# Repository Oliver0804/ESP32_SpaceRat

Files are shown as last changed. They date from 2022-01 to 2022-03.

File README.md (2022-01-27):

# 此項目參考 
[ElectronicCats/SpaceRat](https://github.com/ElectronicCats/mpu6050)
# 項目內容

參考SpaceRat進行程序開發，於ESP32實現BLE HID為主要功能，
搭配EC12旋轉編碼器與MPU6500進行滑鼠控制。

### 準備材料

- ESP32
- MPU6500 (MPU6050)
- LCD Moudle SSD1308 I2C 0.96
- EC12/11
-
### 接線方式

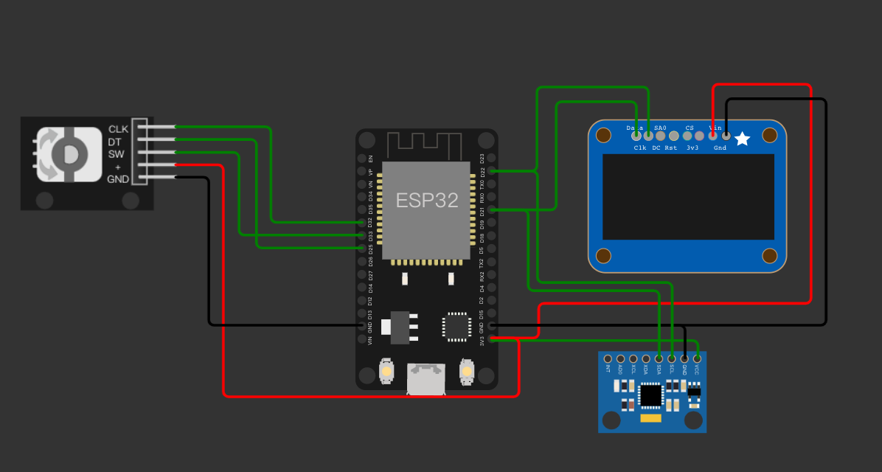
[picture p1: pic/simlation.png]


### TODO List
- [ ] 加速動控制鼠標功能
- [ ] 低功耗機制 需搭配1.5V升壓3.3V
- [ ] OLED選單功能編寫
- [ ] 加速度校正機制

### library安裝
檔案放於Arduino library 

To install this library:

 - install it using the Arduino Library manager ("Sketch" -> "Include
   Library" -> "Manage Libraries..."), or
 - download a zipfile from github using the "Download ZIP" button and
   install it using the IDE ("Sketch" -> "Include Library" -> "Add .ZIP
   Library..."
 - clone this git repository into your sketchbook/libraries folder.

For more info, see https://www.arduino.cc/en/Guide/Libraries

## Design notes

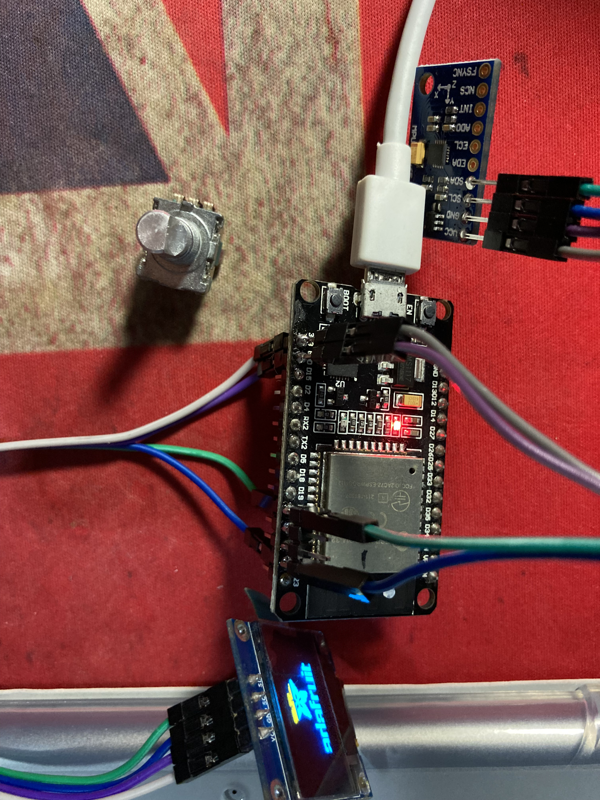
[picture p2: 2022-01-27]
pic/ESP32接線記錄.jpeg

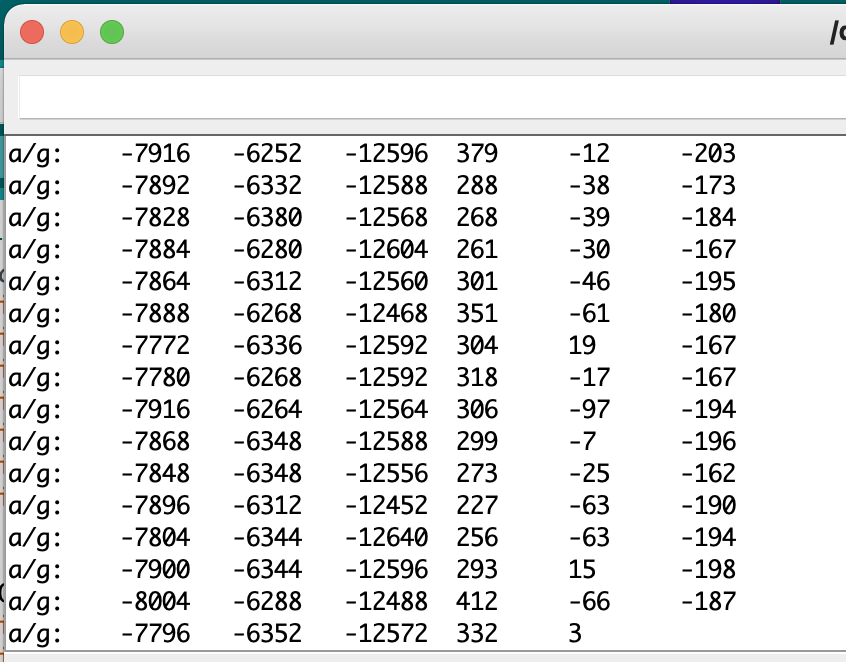
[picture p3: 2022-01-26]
pic/MPU6500數據.png

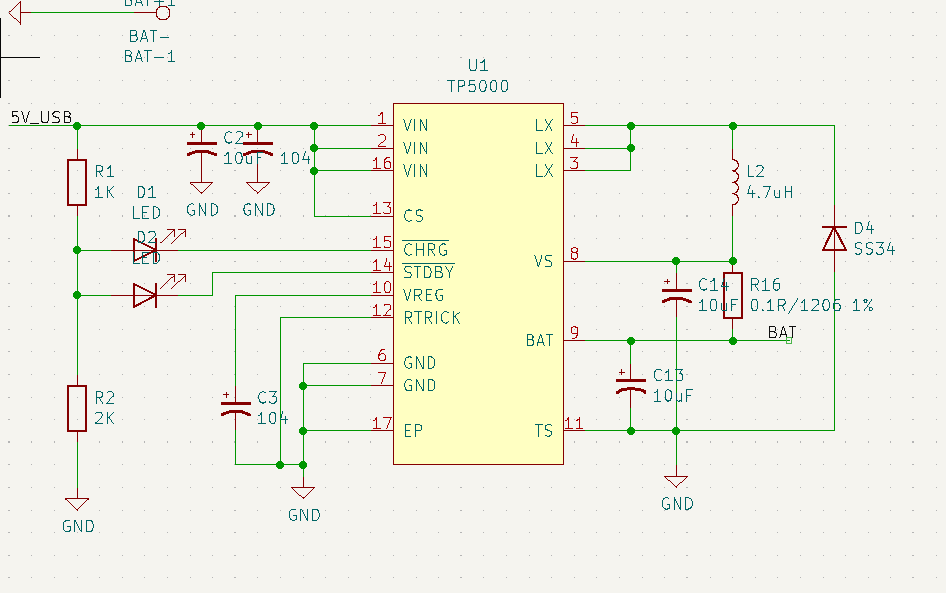
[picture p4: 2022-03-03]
pic/截圖 2022-03-03 下午11.47.27.png

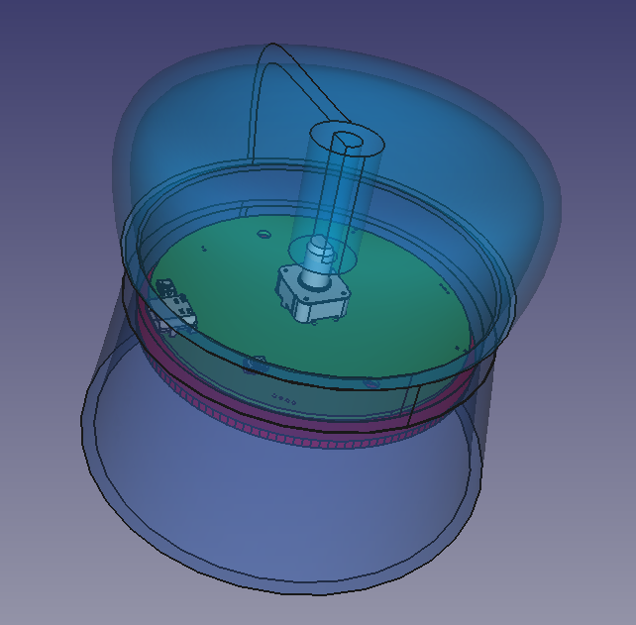
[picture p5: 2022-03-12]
pic/截圖 2022-03-12 下午12.53.13.png

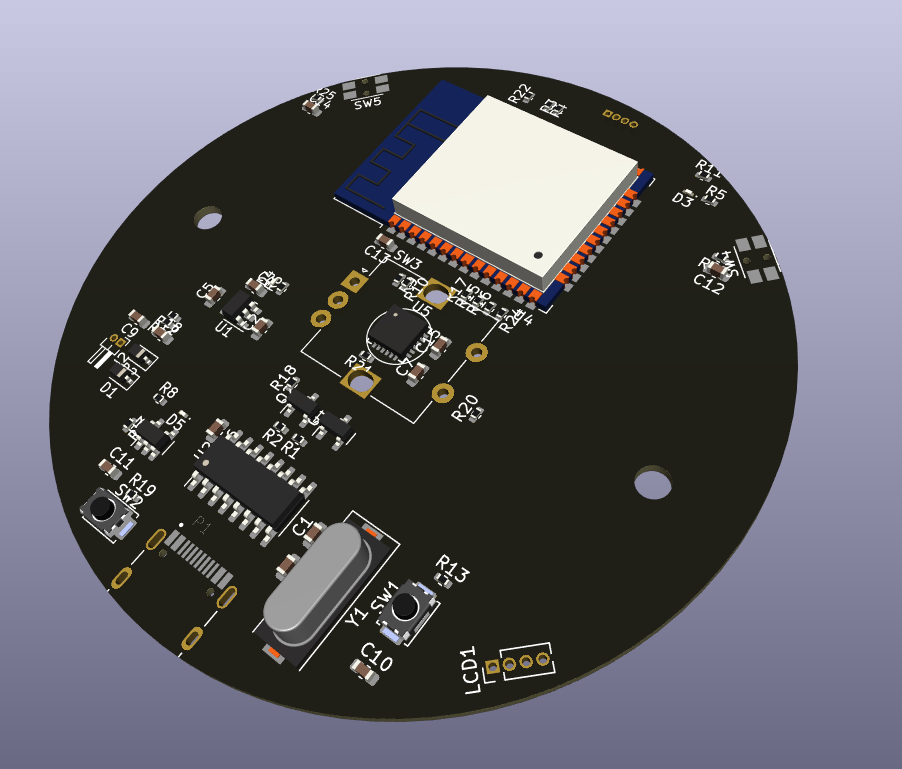
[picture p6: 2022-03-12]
pic/截圖 2022-03-12 下午12.54.49.png

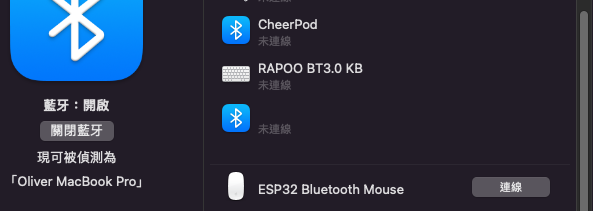
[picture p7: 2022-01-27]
pic/BLEHID測試.png

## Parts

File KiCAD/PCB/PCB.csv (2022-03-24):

Comment | Designator | Footprint | LCSC
22p | C1,C3 | Capacitor_SMD:C_0603_1608Metric
0.1uF | C10,C11,C12,C14,C15 | Capacitor_SMD:C_0603_1608Metric
10nF | C13 | Capacitor_SMD:C_0603_1608Metric
4.7uF | C2,C6,C8 | Capacitor_SMD:C_0603_1608Metric
470pF | C4 | Capacitor_SMD:C_0603_1608Metric
2.2uF | C5 | Capacitor_SMD:C_0603_1608Metric
10uF | C7 | Capacitor_SMD:C_0603_1608Metric
100pF | C9 | Capacitor_SMD:C_0603_1608Metric
D | D1,D2 | Diode_SMD:D_SOD-323
LED | D3,D4,D5 | LED_SMD:LED_0201_0603Metric
Conn_01x04 | J1 | Connector_PinHeader_1.00mm:PinHeader_1x04_P1.00mm_Horizontal
Conn_01x02 | J2 | Connector_PinHeader_1.00mm:PinHeader_1x02_P1.00mm_Horizontal
Conn_01x04 | LCD1 | Connector_PinHeader_1.27mm:PinHeader_1x04_P1.27mm_Vertical
USB_C_Plug | P1 | Connector_USB:HRI_TYPE_C
Q_NPN_EBC | Q1,Q2 | Package_TO_SOT_SMD:SOT-23
R | R1,R2,R5,R6,R15,R16,R17 | Resistor_SMD:R_0402_1005Metric
1M | R12 | Resistor_SMD:R_0402_1005Metric
10K | R13,R19 | Resistor_SMD:R_0402_1005Metric
1MR | R14 | Resistor_SMD:R_0402_1005Metric
10KR | R20 | Resistor_SMD:R_0402_1005Metric
NC | R21 | Resistor_SMD:R_0402_1005Metric
330R | R22,R24 | Resistor_SMD:R_0402_1005Metric
4.7K | R3,R9,R10,R23,R25 | Resistor_SMD:R_0402_1005Metric
1K | R4 | Resistor_SMD:R_0402_1005Metric
2K | R7 | Resistor_SMD:R_0402_1005Metric
470R | R8,R11,R18 | Resistor_SMD:R_0402_1005Metric
SW_Push | SW1,SW2 | Button_Switch_SMD:SW_Push_SPST_NO_Alps_SKRK
RotaryEncoder_Switch | SW3 | Rotary_Encoder:RotaryEncoder_Alps_EC12E-Switch_Vertical_H20mm
SW_Push | SW4,SW5 | Button_Switch_SMD:SW_SPST_EVQP7C
MIC5219-3.3YM5 | U1 | Package_TO_SOT_SMD:SOT-23-5
CH340G | U2 | Package_SO:SOIC-16_3.9x9.9mm_P1.27mm
MCP73832-5-OT | U3 | Package_TO_SOT_SMD:SOT-23-5
ESP32-WROOM-32D | U4 | RF_Module:ESP32-WROOM-32
MPU-6050 | U5 | Sensor_Motion:InvenSense_QFN-24_4x4mm_P0.5mm
12Mhz | Y1 | Crystal:Crystal_SMD_HC49-SD

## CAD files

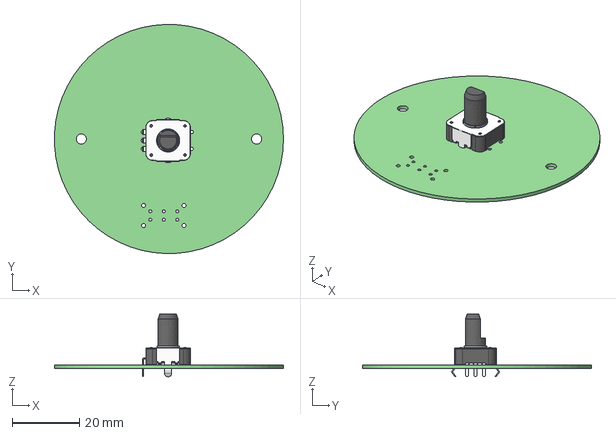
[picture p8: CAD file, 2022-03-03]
KiCAD/PCB/PCB.step
68.0 x 68.0 x 18.6 mm
PCB PCB

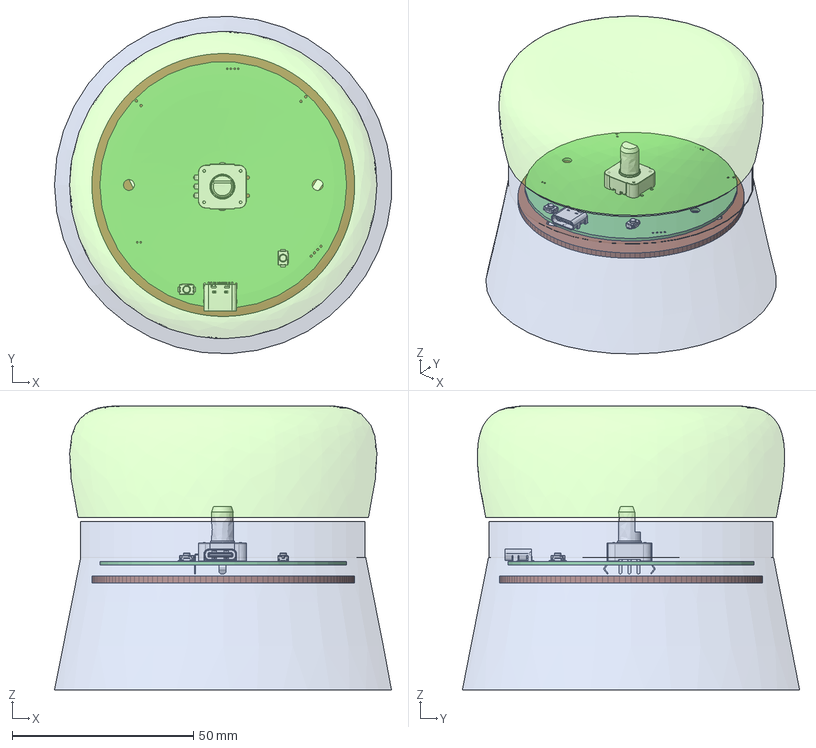
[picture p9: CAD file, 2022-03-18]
STL/dimmer.FCStd
92.8 x 92.9 x 78.2 mm
Orthoplanar_Spring001 (Solid)002
PCB PCB

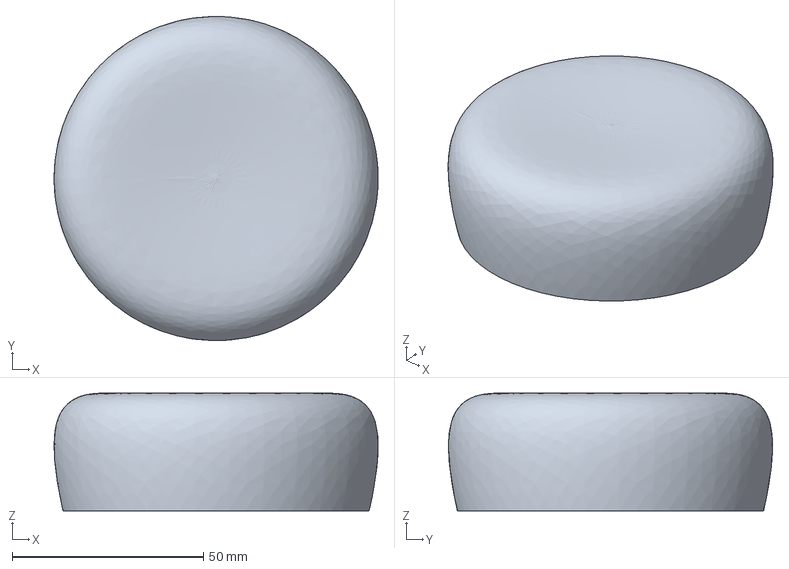
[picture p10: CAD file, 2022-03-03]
STL/蘑菇頭.FCStd
84.6 x 84.6 x 30.8 mm

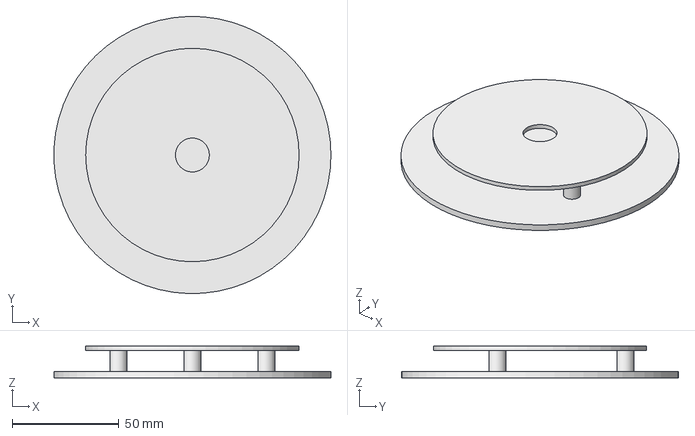
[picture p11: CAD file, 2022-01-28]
STL/SpaceRat.FCStd
129.9 x 130.0 x 15.0 mm

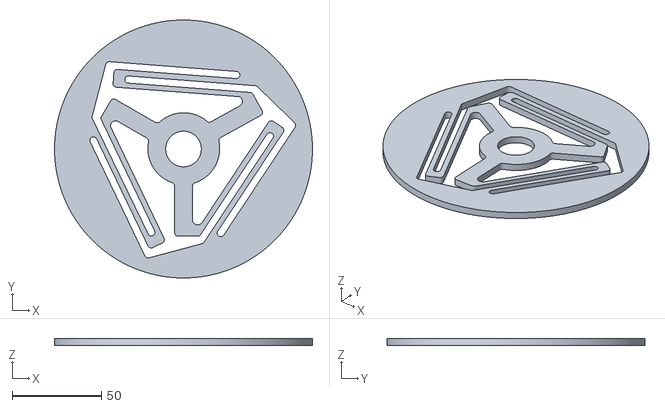
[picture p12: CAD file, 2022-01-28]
STL/Orthoplanar_Spring.stl
144.8 x 144.8 x 3.81

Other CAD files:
STL/Unnamed-Orthoplanar_Spring.dxf

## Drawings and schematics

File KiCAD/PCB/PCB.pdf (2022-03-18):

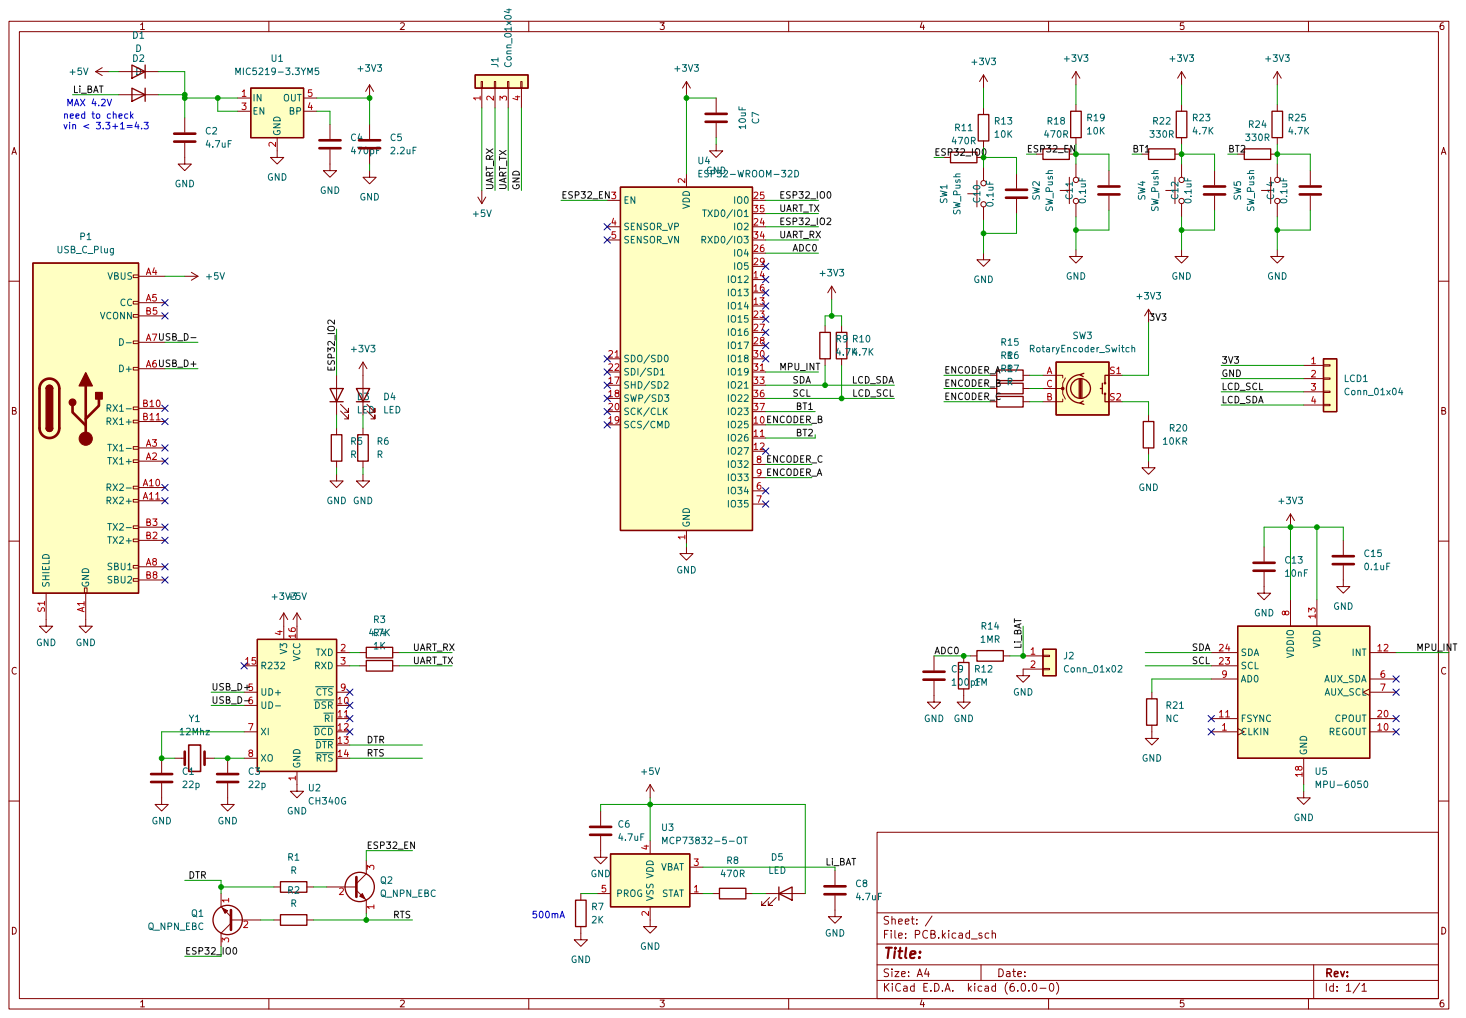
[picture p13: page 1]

2 EN 3 BP 4 OUT 5 U1 MIC5219-3.3YM5 GND C12 0.1uF R20

2 SCK/CLK 20 SDO/SD0 21 SDI/SD1 22

1 ~{DSR}10 ~{RI}11 ~{DCD}12 ~{DTR}13 ~{RTS}14 R232 15 VCC 16 TXD 2 RXD 3 V3

4 UD+ 5 UD- 6 XI 7 XO 8 ~{CTS} 9 U2CH340G

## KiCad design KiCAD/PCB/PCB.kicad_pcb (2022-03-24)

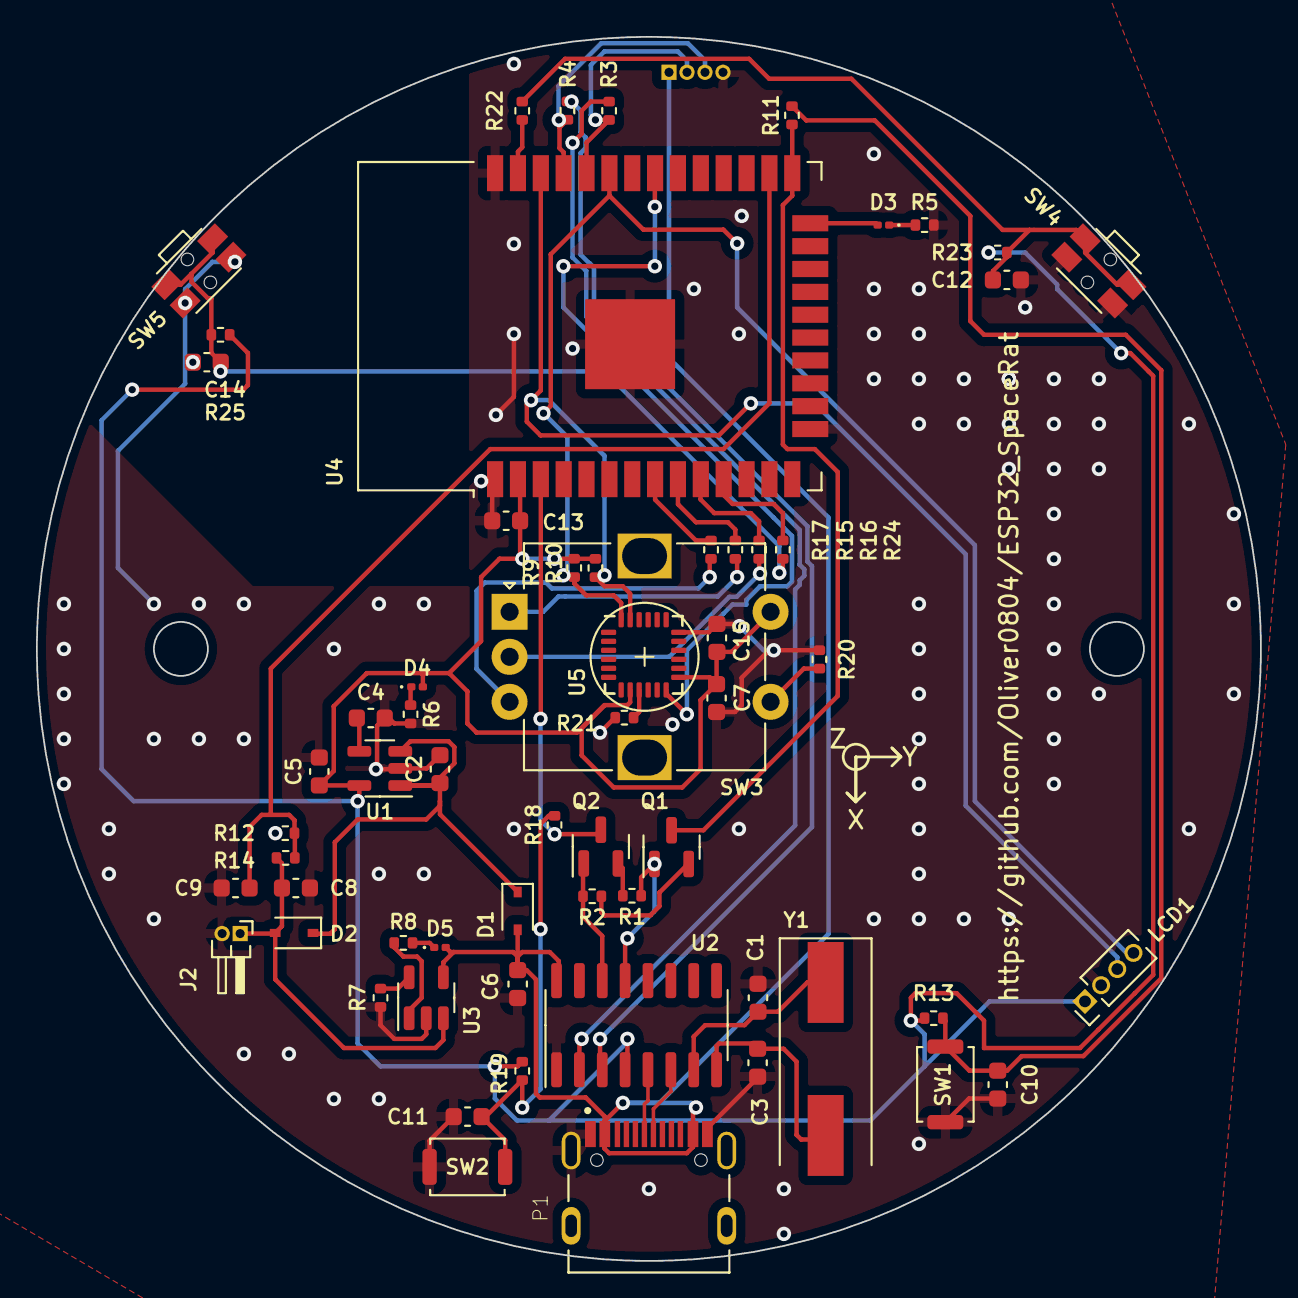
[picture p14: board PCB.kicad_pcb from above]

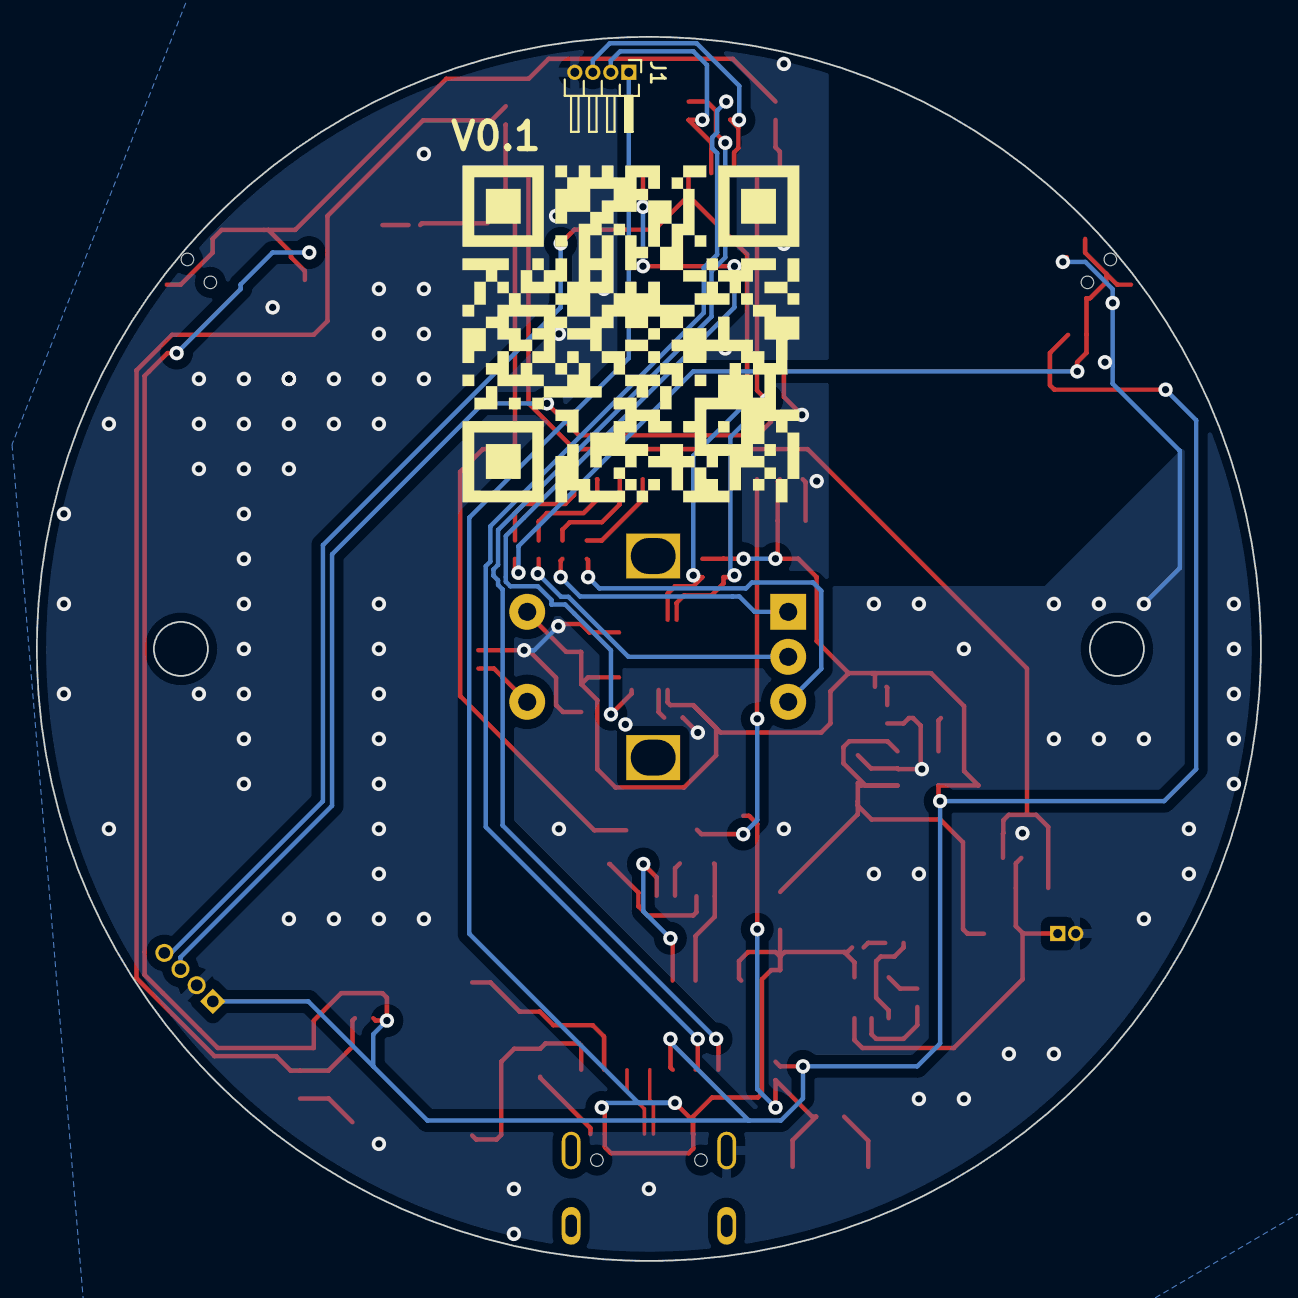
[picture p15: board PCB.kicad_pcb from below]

Board: 2 copper layers, 68.0 x 68.0 mm, 63 parts (2 on the bottom side), 44 nets.

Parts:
C1, C3: 22p; C_0603_1608Metric
C2, C6, C8: 4.7uF; C_0603_1608Metric
C4: 470pF; C_0603_1608Metric
C5: 2.2uF; C_0603_1608Metric
C7: 10uF; C_0603_1608Metric
C9: 100pF; C_0603_1608Metric
C10, C11, C12, C14, C15: 0.1uF; C_0603_1608Metric
C13: 10nF; C_0603_1608Metric
D1, D2: D; D_SOD-323
D3, D4, D5: LED; LED_0201_0603Metric
J1: Conn_01x04; PinHeader_1x04_P1.00mm_Horizontal
J2: Conn_01x02; PinHeader_1x02_P1.00mm_Horizontal
LCD1: Conn_01x04; PinHeader_1x04_P1.27mm_Vertical
P1: USB_C_Plug; HRI_TYPE_C
Q1, Q2: Q_NPN_EBC; SOT-23
R1, R2, R5, R6, R15, R16, R17: R; R_0402_1005Metric
R3, R9, R10, R23, R25: 4.7K; R_0402_1005Metric
R4: 1K; R_0402_1005Metric
R7: 2K; R_0402_1005Metric
R8, R11, R18: 470R; R_0402_1005Metric
R12: 1M; R_0402_1005Metric
R13, R19: 10K; R_0402_1005Metric
R14: 1MR; R_0402_1005Metric
R20: 10KR; R_0402_1005Metric
R21: NC; R_0402_1005Metric
R22, R24: 330R; R_0402_1005Metric
SW1, SW2: SW_Push; SW_Push_SPST_NO_Alps_SKRK
SW3: RotaryEncoder_Switch; RotaryEncoder_Alps_EC12E-Switch_Vertical_H20mm
SW4, SW5: SW_Push; SW_SPST_EVQP7C
U1: MIC5219-3.3YM5; SOT-23-5
U2: CH340G; SOIC-16_3.9x9.9mm_P1.27mm
U3: MCP73832-5-OT; SOT-23-5
U4: ESP32-WROOM-32D; ESP32-WROOM-32
U5: MPU-6050; InvenSense_QFN-24_4x4mm_P0.5mm
V0.1: LOGO
Y1: 12Mhz; Crystal_SMD_HC49-SD

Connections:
+3V3: C5.1, C7.1, C13.1, C15.1, D4.2 (A), LCD1.1, R9.1, R10.1, R13.1, R19.1, R23.1, R25.1, SW3.S1, U1.5 (OUT), U2.4 (V3), U4.2 (VDD), U5.8 (VDDIO), U5.13 (VDD)
+5V: C6.1, D1.2 (A), D5.2 (A), J1.1, P1.A4 (VBUS), P1.B4 (VBUS), U2.16 (VCC), U3.4 (VDD)
/ADC0: C9.1, R12.1, R14.1, U4.26 (IO4)
/BT1: R22.1, U4.37 (IO23)
/BT2: R24.1, U4.11 (IO26)
/DTR: Q1.1 (E), R1.1, U2.13 (~DTR)
/ENCODER_A: R15.1, U4.9 (IO33)
/ENCODER_B: R16.1, U4.10 (IO25)
/ENCODER_C: R17.1, U4.8 (IO32)
/ESP32_EN: Q2.3 (C), R18.1, U4.3 (EN)
/ESP32_IO0: Q1.3 (C), R11.1, U4.25 (IO0)
/ESP32_IO2: D3.2 (A), U4.24 (IO2)
/LCD_SCL: LCD1.3, R10.2, U4.36 (IO22), U5.23 (SCL)
/LCD_SDA: LCD1.4, R9.2, U4.33 (IO21), U5.24 (SDA)
/Li_BAT: C8.1, D2.2 (A), J2.1, R14.2, U3.3 (VBAT)
/MPU_INT: U4.31 (IO19), U5.12 (INT)
/RTS: Q2.1 (E), R2.2, U2.14 (~RTS)
/UART_RX: J1.2, R3.2, U4.34 (RXD0/IO3)
/UART_TX: J1.3, R4.2, U4.35 (TXD0/IO1)
/USB_D+: P1.A6 (D+), U2.5 (UD+)
/USB_D-: P1.A7 (D-), U2.6 (UD-)
GND: C1.2, C2.2, C3.2, C4.2, C5.2, C6.2, C7.2, C8.2, C9.2, C10.1, C11.1, C12.1, C13.2, C14.1, C15.2, J1.4, J2.2, LCD1.2, P1.A1 (GND), P1.B1 (GND), P1.S1 (SHIELD), R5.2, R6.2, R7.2, R12.2, R20.2, R21.2, SW1.1, SW2.1, SW4.1, SW5.1, U1.2 (GND), U2.1 (GND), U3.2 (VSS), U4.1 (GND), U4.15 (GND), U4.38 (GND), U4.39 (GND), U5.18 (GND)
unnamed: C1.1, U2.7 (XI), Y1.1
unnamed: C2.1, D1.1 (K), D2.1 (K), U1.1 (IN), U1.3 (EN)
unnamed: C3.1, U2.8 (XO), Y1.2
unnamed: C4.1, U1.4 (BP)
unnamed: C10.2, R11.2, R13.2, SW1.2
unnamed: C11.2, R18.2, R19.2, SW2.2
unnamed: C12.2, R22.2, R23.2, SW4.2
unnamed: C14.2, R24.2, R25.2, SW5.2
unnamed: D3.1 (K), R5.1
unnamed: D4.1 (K), R6.1
unnamed: D5.1 (K), R8.2
unnamed: Q1.2 (B), R2.1
unnamed: Q2.2 (B), R1.2
unnamed: R3.1, U2.2 (TXD)
unnamed: R4.1, U2.3 (RXD)
unnamed: R7.1, U3.5 (PROG)
unnamed: R8.1, U3.1 (STAT)
unnamed: R15.2, SW3.A
unnamed: R16.2, SW3.C
unnamed: R17.2, SW3.B
unnamed: R20.1, SW3.S2
unnamed: R21.1, U5.9 (AD0)

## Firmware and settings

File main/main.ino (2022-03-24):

#include "AiEsp32RotaryEncoder.h"
#include "Arduino.h"

#include <SPI.h>
#include <Wire.h>
#include <Adafruit_GFX.h>
#include <Adafruit_SSD1306.h>

#define LED_PIN 2
bool blinkState = false;


// I2Cdev and MPU6050 must be installed as libraries, or else the .cpp/.h files
// for both classes must be in the include path of your project
#include "I2Cdev.h"
#include "MPU6050.h"
MPU6050 accelgyro;
int16_t ax, ay, az;
int16_t gx, gy, gz;
int16_t offset_ax, offset_ay , offset_az;


void setup() {
  Serial.begin(115200);
  encoder_init();

  mpu6050_init();
  bleHID_init();
  initOffset(5);
}


void loop() {
  rotary_loop();
  //mpu6050_read(1);
//  bleHID_control();
   //Serial.print(ax); Serial.print("\t");
}

void rat2hid(){
  
  }

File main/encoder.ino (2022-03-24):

/*
  connecting Rotary encoder
  Rotary encoder side    MICROCONTROLLER side
  -------------------    ---------------------------------------------------------------------
  CLK (A pin)            any microcontroler intput pin with interrupt -> in this example pin 32
  DT (B pin)             any microcontroler intput pin with interrupt -> in this example pin 21
  SW (button pin)        any microcontroler intput pin with interrupt -> in this example pin 25
  GND - to microcontroler GND
  VCC                    microcontroler VCC (then set ROTARY_ENCODER_VCC_PIN -1)
***OR in case VCC pin is not free you can cheat and connect:***
  VCC                    any microcontroler output pin - but set also ROTARY_ENCODER_VCC_PIN 25
                        in this example pin 25
*/
/*
 * ESP32因D21腳被I2C占用，占以D25代用
 * 按下功能改用D33
 */
#if defined(ESP8266)
#define ROTARY_ENCODER_A_PIN D6
#define ROTARY_ENCODER_B_PIN D5
#define ROTARY_ENCODER_BUTTON_PIN D7
#else
#define ROTARY_ENCODER_A_PIN 32
#define ROTARY_ENCODER_B_PIN 33
#define ROTARY_ENCODER_BUTTON_PIN 25
#endif
#define ROTARY_ENCODER_VCC_PIN -1 /* 27 put -1 of Rotary encoder Vcc is connected directly to 3,3V; else you can use declared output pin for powering rotary encoder */

#define ROTARY_ENCODER_STEPS 4



//instead of changing here, rather change numbers above
AiEsp32RotaryEncoder rotaryEncoder = AiEsp32RotaryEncoder(ROTARY_ENCODER_A_PIN, ROTARY_ENCODER_B_PIN, ROTARY_ENCODER_BUTTON_PIN, ROTARY_ENCODER_VCC_PIN, ROTARY_ENCODER_STEPS);


void rotary_onButtonClick()
{
  static unsigned long lastTimePressed = 0;
  //ignore multiple press in that time milliseconds
  if (millis() - lastTimePressed < 500)
  {
    return;
  }
  lastTimePressed = millis();
  Serial.print("button pressed ");
  Serial.print(millis());
  Serial.println(" milliseconds after restart");
}

void rotary_loop()
{
  //dont print anything unless value changed
  if (rotaryEncoder.encoderChanged())
  {
    Serial.print("Value: ");
    Serial.println(rotaryEncoder.readEncoder());
  }
  if (rotaryEncoder.isEncoderButtonClicked())
  {
    rotary_onButtonClick();
  }
}

void IRAM_ATTR readEncoderISR()
{
  rotaryEncoder.readEncoder_ISR();
}

void encoder_init() {
  //we must initialize rotary encoder
  rotaryEncoder.begin();
  rotaryEncoder.setup(readEncoderISR);
  //set boundaries and if values should cycle or not
  //in this example we will set possible values between 0 and 1000;
  bool circleValues = false;
  rotaryEncoder.setBoundaries(0, 1000, circleValues); //minValue, maxValue, circleValues true|false (when max go to min and vice versa)

  /*Rotary acceleration introduced 25.2.2021.
     in case range to select is huge, for example - select a value between 0 and 1000 and we want 785
     without accelerateion you need long time to get to that number
     Using acceleration, faster you turn, faster will the value raise.
     For fine tuning slow down.
  */
  //rotaryEncoder.disableAcceleration(); //acceleration is now enabled by default - disable if you dont need it
  rotaryEncoder.setAcceleration(250); //or set the value - larger number = more accelearation; 0 or 1 means disabled acceleration
  lcd_init();
}

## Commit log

2022-01-26 MPU6500 LCD EC12 BLE HID編碼器以整合待測試
2022-01-27 提升代碼可讀性
2022-01-27 整理目錄結構
2022-01-27 add readme and 接線圖
2022-01-27 優化個項目基礎功能
2022-01-27 加入i2c scanner工具
2022-01-28 更新Ble HID庫 加入免彈簧機構方式
    [Orthoplanar_Spring.stl, SpaceRat.FCStd, Unnamed-Orthoplanar_Spring.dxf]
2022-03-02 添加蘑菇頭FreeCAD檔案
    [蘑菇頭.FCStd]
2022-03-03 fixed error size
    [dimmer.FCStd, 蘑菇頭.FCStd]
2022-03-03 update 外殼彈簧
    [dimmer.FCStd]
2022-03-03 1 kicad初步繪製 2 freecad導入電路板尺寸 3 增加datasheet資料夾
    [PCB.kicad_pcb, PCB.kicad_sch, PCB.step]
2022-03-08 原理圖第一版完成
    [PCB.kicad_pcb, PCB.kicad_sch, dimmer.FCStd]
2022-03-12 完成佈件
    [PCB.kicad_pcb, PCB.kicad_sch, dimmer.FCStd]
2022-03-18 完成佈線
    [PCB.kicad_pcb, PCB.kicad_sch, dimmer.FCStd]
2022-03-24 更新第二版原理圖
    [PCB-B_Cu.gbr, PCB-B_Mask.gbr, PCB-B_Paste.gbr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]
